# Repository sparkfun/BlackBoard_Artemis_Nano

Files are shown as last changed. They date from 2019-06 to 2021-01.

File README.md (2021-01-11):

**NOTE:** *This product has been retired from our catalog. There is an updated RedBoard version available: [DEV-15443](https://www.sparkfun.com/products/15443). If you are looking for more up-to-date info, please check out some of these resources to see how other users are still hacking and improving on this product version.*

* *[SparkFun Artemis Forum](https://forum.sparkfun.com/viewforum.php?f=167)*
* *[Comments Here on GitHub](https://github.com/sparkfun/BlackBoard_Artemis_Nano/issues)*

SparkFun BlackBoard Artemis Nano
============================

[SparkFun BlackBoard Artemis Nano  
*SparkFun BlackBoard Artemis Nano (SPX-15411)*](https://www.sparkfun.com/products/15411)

We like to joke the Artemis Nano is a party on the front and business on the back. And that's by design! All the important LEDs, connectors, labels, and buttons are presented on the front for the best user experience with all the supporting circuitry on the rear of the board. The BlackBoard Artemis Nano is a minimal but extremely handy implementation of the Artemis module. A light weight, 0.8mm thick PCB, with on board lipo-battery charging and a Qwiic connector, this board is easy to implement into very small projects. A dual row of ground connections make it easy to add lots of buttons, LEDs, and anything that requires its own GND connection. At the same time, the board is breadboard compatible! 

A modern USB-C connector makes programming easy. The Nano is fully compatible with the SparkFun's Arduino core and can be programmed easily under the Arduino IDE. We've also exposed the JTAG connector for more advanced users who prefer to use the power and speed of professional tools. If you're looking for a simple, cost-effective board to replace your aging Arduino Uno or Arduino Nano, look no further. We've even added a digital MEMS microphone for folks wanting to experiment with always-on voice commands with TensorFlow and machine learning.
 
With 1M flash and 384k RAM you'll have plenty of room for your sketches. The Artemis module runs at 48MHz with a 96MHz turbo mode available and with Bluetooth to boot!

The SparkFun Artemis Nano is an incredibly flexible device for a small footprint but if you're looking for all the bells and whistles, be sure to checkout our BlackBoard and ATP footprints for even more I/O and capabilities.

Repository Contents
-------------------
* **/Hardware** - Eagle design files (.brd, .sch)

Documentation
-------------------

* **[Hookup Guide for the BlackBoard Artemis Nano](https://learn.sparkfun.com/tutorials/hookup-guide-for-the-blackboard-artemis-nano)**
* **[Designing with the SparkFun Artemis](https://learn.sparkfun.com/tutorials/designing-with-the-sparkfun-artemis)** - Layout and design considerations when using the Artemis module.
* **[Artemis Development with Arduino](https://learn.sparkfun.com/tutorials/artemis-development-with-arduino)** - Introduction to the Arduino core for the Artemis Module.
* **[Ambiq Apollo3 SDK SetUp](https://learn.sparkfun.com/tutorials/using-sparkfun-edge-board-with-ambiq-apollo3-sdk)** - Getting set up with the Apollo3 Software Development Kit.
* **[CH340E USB to serial IC Drivers](https://www.sparkfun.com/ch340)**
* **[SparkFun Fritzing repo](https://github.com/sparkfun/Fritzing_Parts)** - Fritzing diagrams for SparkFun products.

License Information
-------------------

This product is _**open source**_! 

Please review the LICENSE.md file for license information. 

If you have any questions or concerns on licensing, please contact techsupport@sparkfun.com.

Please use, reuse, and modify these files as you see fit. Please maintain attribution to SparkFun Electronics and release any derivative under the same license.

Distributed as-is; no warranty is given.

- Your friends at SparkFun.

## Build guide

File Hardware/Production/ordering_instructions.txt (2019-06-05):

panel size, 115x97mm
PCB thickness, 0.8mm
number of layers, 4
soldermask color, Red
silkscreen color, White
oz copper, 1oz
finish, HASL lead free
stencils, top+bottom
pcs per panel, 8
min trace width, 0.152400mm / 0.006000in
min drill size, 0.304800mm / 0.012000in
filename to layer stackup 1/2/3/4: GTL, GL2, GL3, GBL

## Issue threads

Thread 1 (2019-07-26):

Cannot upload code

iplayfast, 2019-07-26:
Using Linux.
Artemis SVL Bootloader

phase:	setup
	cleared startup blip
/dev/ttyUSB0 is currently open. Please close any other terminal programs that may be using /dev/ttyUSB0 and try again.
Sketch uses 7348 bytes (0%) of program storage space. Maximum is 960000 bytes.
/home/chris/.arduino15/packages/SparkFun/hardware/apollo3/1.0.4/tools/artemis/linux/artemis_svl /dev/ttyUSB0 -f /tmp/arduino_build_995052/Blink.ino.bin -b 921600 -v

Artemis SVL Bootloader

phase:	setup
	cleared startup blip
/dev/ttyUSB0 is currently open. Please close any other terminal programs that may be using /dev/ttyUSB0 and try again

Opening serial monitor and setting the baud to 9600
shows communication is ok. Shows errors on pins which I'm assuming is from test software missing test bed.

iplayfast, 2019-07-26:
A similar problem with another board was due to flow control problems was worked around by the following python code
`import serial.tools.miniterm
serial.tools.miniterm.main(default_port='/dev/ttyACM0', default_baudrate=115200, default_dtr=False, default_rts=False)

`
Not really a good solution. But perhaps will help you resolve this issue.

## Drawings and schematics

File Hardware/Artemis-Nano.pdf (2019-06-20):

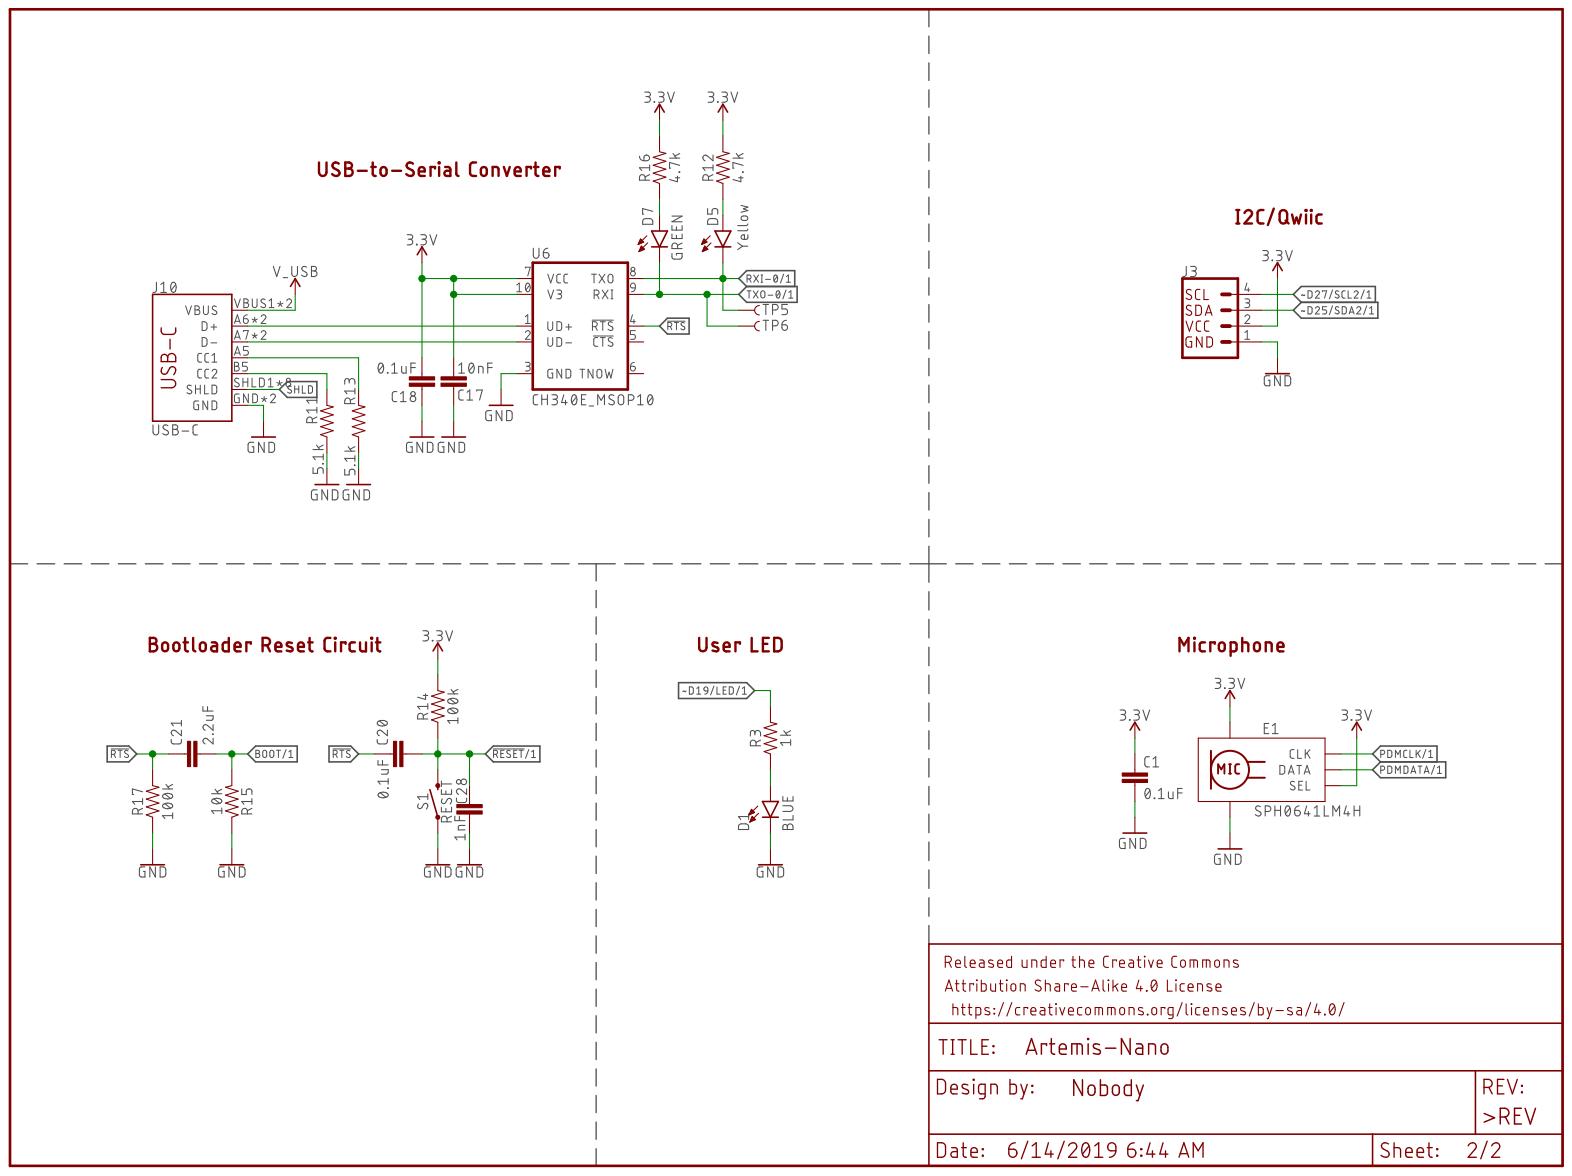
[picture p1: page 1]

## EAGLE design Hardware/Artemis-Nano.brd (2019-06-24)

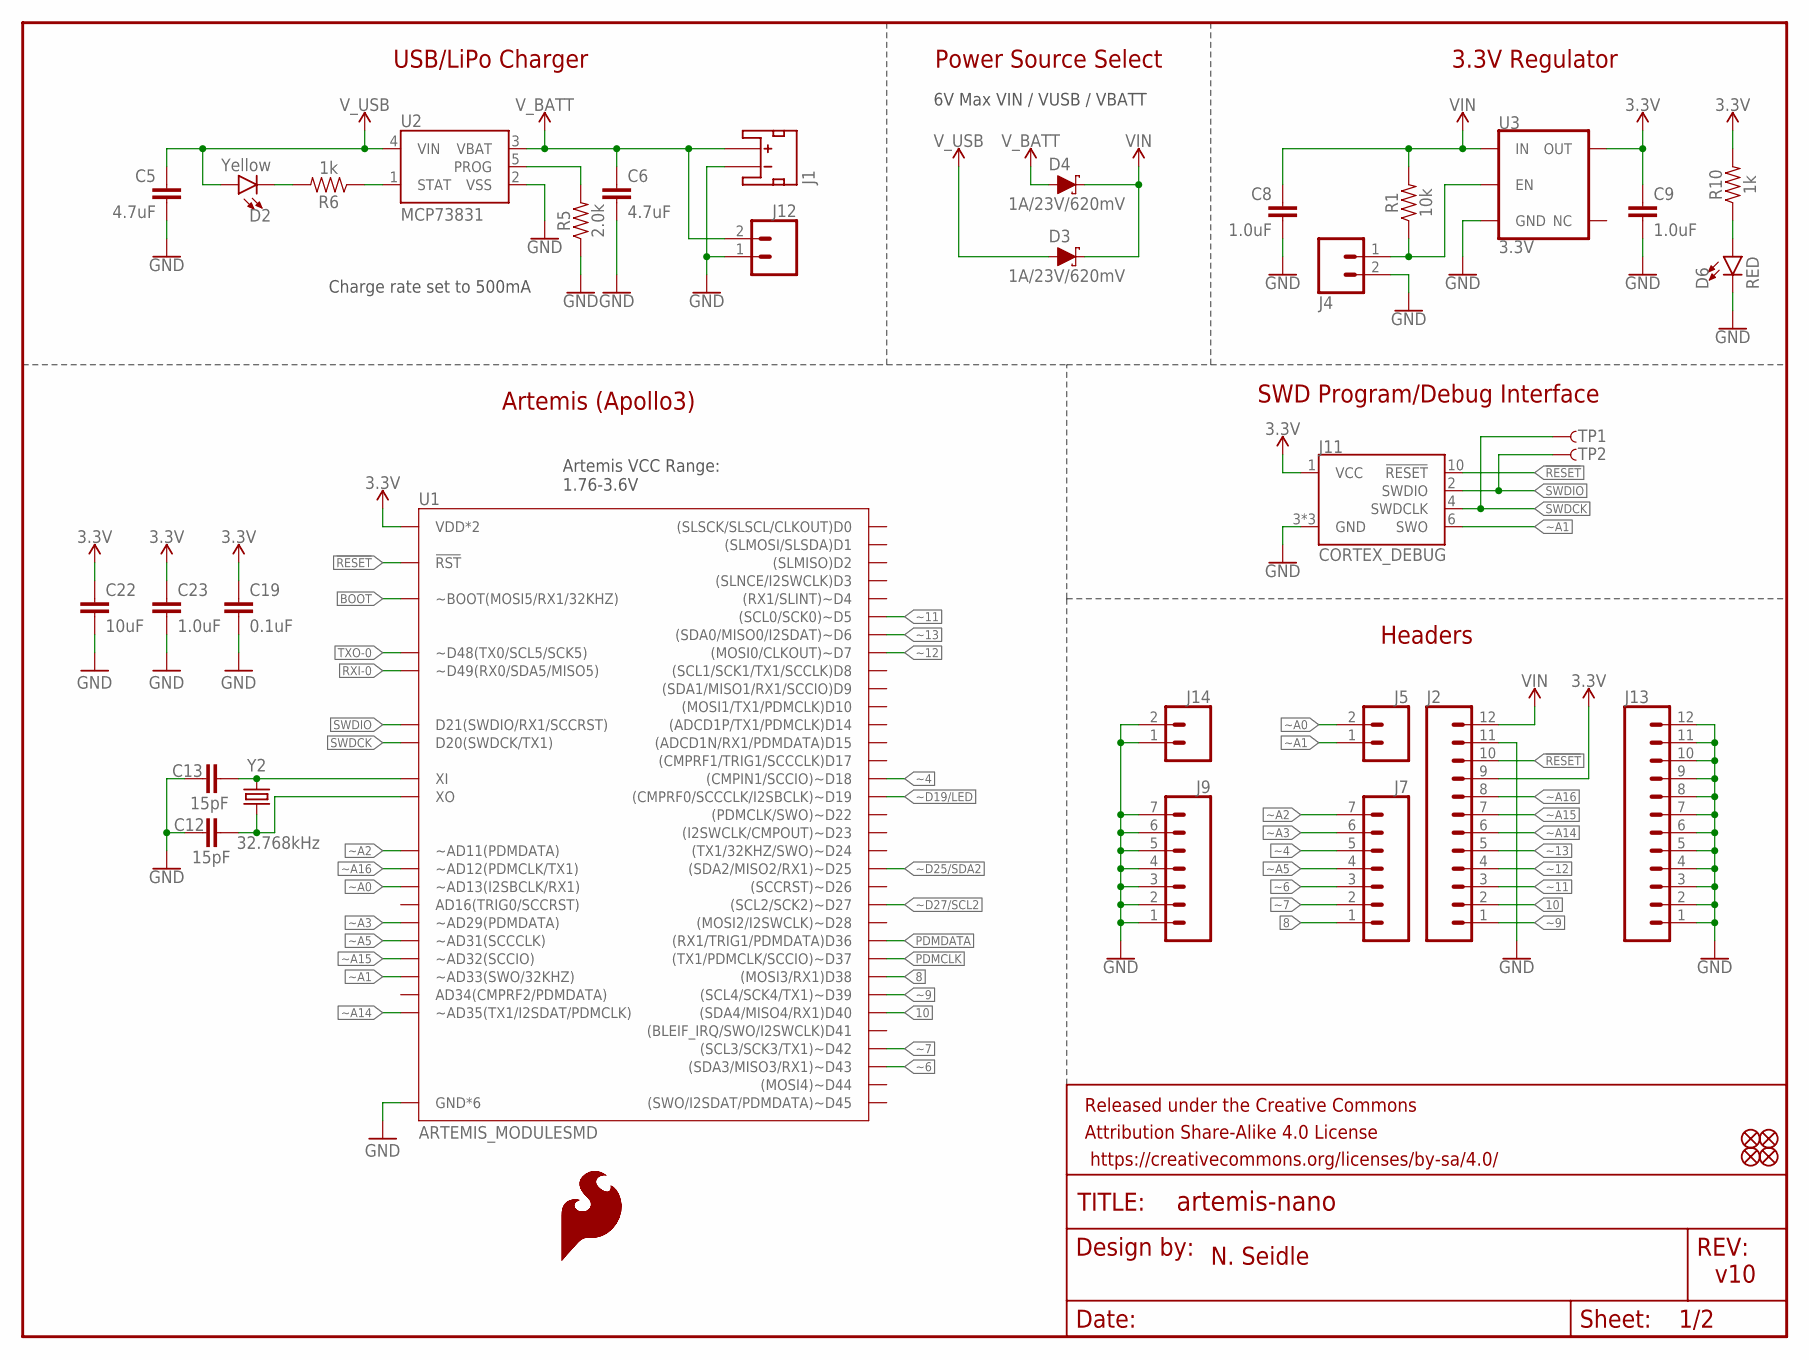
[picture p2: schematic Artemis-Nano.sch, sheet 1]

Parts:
C5, C6: 4.7uF; 0603
C8, C9, C23: 1.0uF; 0402-TIGHT
C12, C13: 15pF; 0603
C19: 0.1uF; 0402-TIGHT
C22: 10uF; 0603
D2: Yellow; LED-0603
D3, D4: 1A/23V/620mV; SOD-323
D6: RED; LED-0603
FD1, FD2, FD3, FD4: FIDUCIALUFIDUCIAL; FIDUCIAL-MICRO
FRAME1: FRAME-LETTER; CREATIVE_COMMONS
J1: JST_2MM_MALE; JST-2-SMD
J2, J13: CONN_12NO_SILK; 1X12_NO_SILK
J4, J5, J12, J14: CONN_021X02_NO_SILK; 1X02_NO_SILK
J7, J9: CONN_07NO_SILK; 1X07_NO_SILK
J11: CORTEX_DEBUG; 2X5-PTH-1.27MM-NO_SILK
LOGO1, LOGO4: SFE_LOGO_FLAME.1_INCH; SFE_LOGO_FLAME_.1
R1: 10k; 0603
R5: 2.0k; 0603
R6, R10: 1k; 0603
TP1, TP2: TEST-POINT3X5; PAD.03X.05
U1: ARTEMIS_MODULESMD; ARTEMIS_FP
U2: MCP73831; SOT23-5
U3: 3.3V; SOT23-5
Y2: 32.768kHz; CRYSTAL-SMD-3.2X1.5MM

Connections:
3.3V: C9.1, C19.2, C22.1, C23.1, J2.9, J11.1 (VCC), R10.2, U1.VDD@36 (VDD*2), U1.VDD@37 (VDD*2), U3.5 (OUT); also elsewhere on the board
8: J7.1, U1.D38 ((MOSI3/RX1)D38)
10: J2.2, U1.D40 ((SDA4/MISO4/RX1)D40)
!RESET: J2.10, J11.10 (!RESET), U1.~RST (!RST); also elsewhere on the board
BOOT: U1.BOOT (~BOOT(MOSI5/RX1/32KHZ)); also elsewhere on the board
GND: C5.2, C6.2, C8.2, C9.2, C12.1, C13.1, C19.1, C22.2, C23.2, D6.C, J1.1 (-), J2.11, J4.2, J9.1, J9.2, J9.3, J9.4, J9.5, J9.6, J9.7, J11.3 (GND), J11.5 (GND), J11.9 (GND), J12.1, J13.1, J13.2, J13.3, J13.4, J13.5, J13.6, J13.7, J13.8, J13.9, J13.10, J13.11, J13.12, J14.1, J14.2, R5.1, U1.GND@1 (GND*6), U1.GND@22 (GND*6), U1.GND@38 (GND*6), U1.GND@39 (GND*6), U1.GND@47 (GND*6), U1.GND@59 (GND*6), U2.2 (VSS), U3.2 (GND); also elsewhere on the board
unnamed: R5.2, U2.5 (PROG)
unnamed: C12.2, U1.XO, Y2.P$2 (2)
unnamed: D2.C, R6.2
unnamed: R6.1, U2.1 (STAT)
unnamed: C13.2, U1.XI, Y2.P$1 (1)
unnamed: D6.A, R10.1
PDMCLK: U1.~D37 ((TX1/PDMCLK/SCCIO)~D37); also elsewhere on the board
PDMDATA: U1.D36 ((RX1/TRIG1/PDMDATA)D36); also elsewhere on the board
RXI-0: U1.RXI-0 (~D49(RX0/SDA5/MISO5)); also elsewhere on the board
SWDCK: J11.4 (SWDCLK), TP1.P$1, U1.SWDCK (D20(SWDCK/TX1))
SWDIO: J11.2 (SWDIO), TP2.P$1, U1.SWDIO (D21(SWDIO/RX1/SCCRST))
TXO-0: U1.TXO-0 (~D48(TX0/SCL5/SCK5)); also elsewhere on the board
VIN: C8.1, D3.C, D4.C, J2.12, R1.2, U3.1 (IN)
VREG_EN: J4.1, R1.1, U3.3 (EN)
V_BATT: C6.1, D4.A, J1.2 (+), J12.2, U2.3 (VBAT)
V_USB: C5.1, D2.A, D3.A, U2.4 (VIN); also elsewhere on the board
~4: J7.5, U1.~D18 ((CMPIN1/SCCIO)~D18)
~6: J7.3, U1.~D43 ((SDA3/MISO3/RX1)~D43)
~7: J7.2, U1.~D42 ((SCL3/SCK3/TX1)~D42)
~9: J2.1, U1.~D39 ((SCL4/SCK4/TX1)~D39)
~11: J2.3, U1.~D5 ((SCL0/SCK0)~D5)
~12: J2.4, U1.D7 ((MOSI0/CLKOUT)~D7)
~13: J2.5, U1.~D6 ((SDA0/MISO0/I2SDAT)~D6)
~A0: J5.2, U1.~AD13 (~AD13(I2SBCLK/RX1))
~A1: J5.1, J11.6 (SWO), U1.~AD33/SWO (~AD33(SWO/32KHZ))
~A2: J7.7, U1.~AD11 (~AD11(PDMDATA))
~A3: J7.6, U1.~AD29 (~AD29(PDMDATA))
~A5: J7.4, U1.~AD31 (~AD31(SCCCLK))
~A14: J2.6, U1.~AD35 (~AD35(TX1/I2SDAT/PDMCLK))
~A15: J2.7, U1.~AD32 (~AD32(SCCIO))
~A16: J2.8, U1.~AD12 (~AD12(PDMCLK/TX1))
~D19/LED: U1.~D19 ((CMPRF0/SCCCLK/I2SBCLK)~D19); also elsewhere on the board
~D25/SDA2: U1.~D25 ((SDA2/MISO2/RX1)~D25); also elsewhere on the board
~D27/SCL2: U1.~D27 ((SCL2/SCK2)~D27); also elsewhere on the board

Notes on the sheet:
v10
N. Seidle
SWD Program/Debug Interface
Headers
Artemis (Apollo3)
USB/LiPo Charger
Power Source Select
3.3V Regulator
Artemis VCC Range: 1.76-3.6V
Charge rate set to 500mA
6V Max VIN / VUSB / VBATT

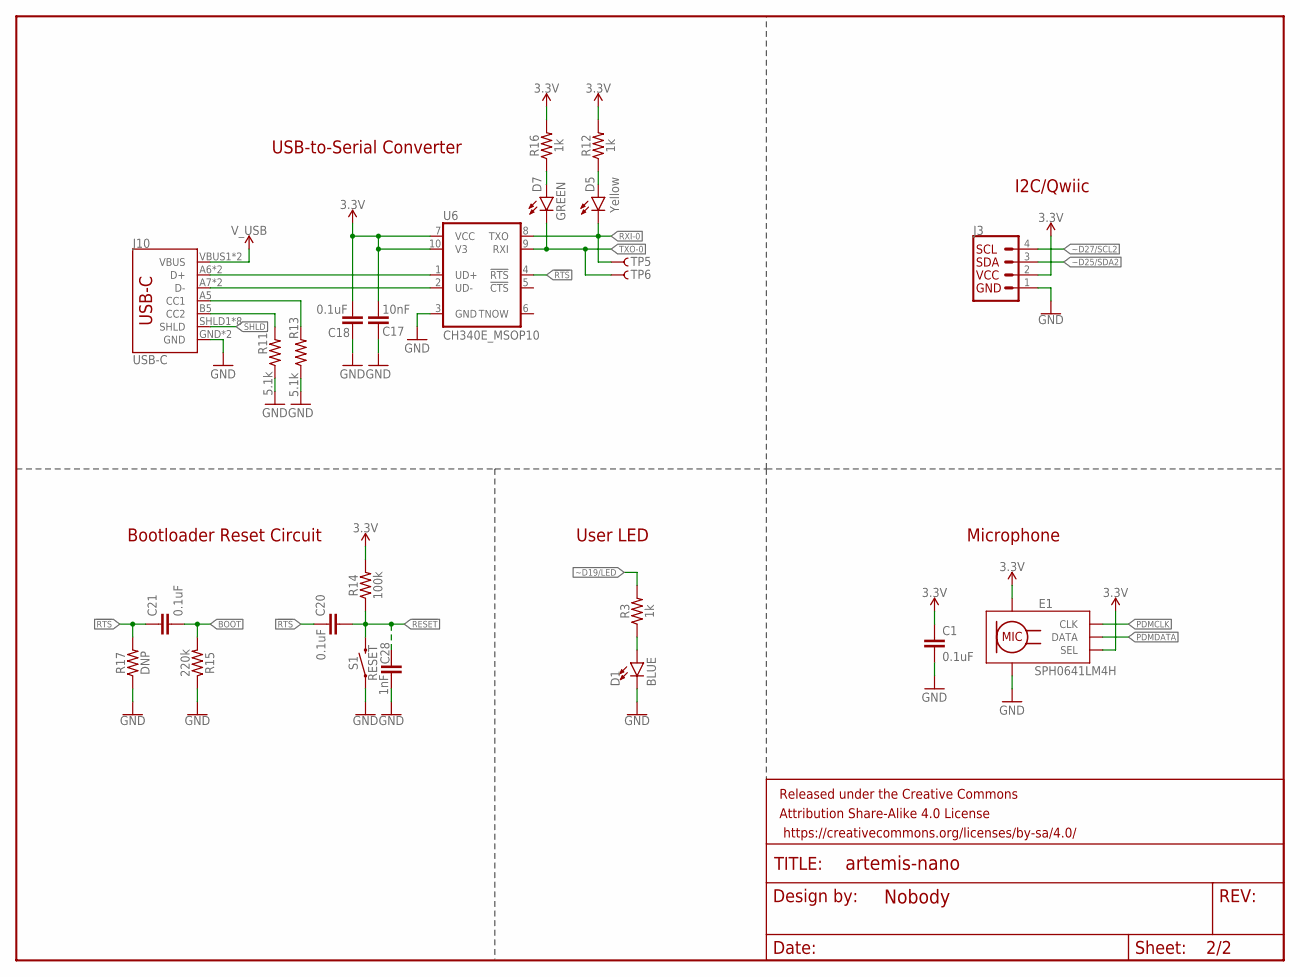
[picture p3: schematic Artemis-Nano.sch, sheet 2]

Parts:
C1: 0.1uF; 0402-TIGHT
C17: 10nF; 0603
C18, C20, C21: 0.1uF; 0603
C28: 1nF; 0603
D1: BLUE; LED-0603
D5: Yellow; LED-0603
D7: GREEN; LED-0603
E1: SPH0641LM4H; SPH0641LM4H-1_MICROPHONE
FRAME2: FRAME-LETTERNO_PACKAGE; DUMMY
J3: QWIIC_CONNECTORJS-1MM; JST04_1MM_RA
J10: USB-C; USB-C-16P
R3, R12, R16: 1k; 0603
R11, R13: 5.1k; 0603
R14: 100k; 0603
R15: 220k; 0603
R17: DNP; 0603
S1: RESET; TACTILE_SWITCH_SMD_4.6X2.8MM
TP5, TP6: TEST-POINT3X5; PAD.03X.05
U6: CH340E_MSOP10; MSOP10

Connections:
3.3V: C1.1, C17.1, C18.1, E1.2 (SEL), E1.5 (VDD), J3.2, R12.2, R14.2, R16.2, U6.7 (VCC), U6.10 (V3); also elsewhere on the board
!RESET: C20.2, C28.1, R14.1, S1.3 (2), S1.4 (2); also elsewhere on the board
!RTS: C20.1, C21.1, R17.2, U6.4 (!RTS)
BOOT: C21.2, R15.2; also elsewhere on the board
CC1: J10.A5 (CC1), R13.2
CC2: J10.B5 (CC2), R11.2
D+1: J10.A6 (D+), J10.B6 (D+), U6.1 (UD+)
D-1: J10.A7 (D-), J10.B7 (D-), U6.2 (UD-)
GND: C1.2, C17.2, C18.2, C28.2, D1.C, E1.3 (GND), E1.6 (GND), E1.7 (GND), E1.8 (GND), J3.1, J10.GND, J10.GND2 (GND), R11.1, R13.1, R15.1, R17.1, S1.1, S1.2 (1), U6.3 (GND); also elsewhere on the board
unnamed: D7.A, R16.1
unnamed: D1.A, R3.1
unnamed: D5.A, R12.1
PDMCLK: E1.4 (CLK); also elsewhere on the board
PDMDATA: E1.1 (DATA); also elsewhere on the board
RXI-0: D5.C, TP5.P$1, U6.8 (TXO); also elsewhere on the board
SHLD: J10.SHLD1 (SHLD), J10.SHLD2 (SHLD), J10.SHLD3 (SHLD), J10.SHLD4 (SHLD), J10.SHLD5 (SHLD), J10.SHLD6 (SHLD), J10.SHLD7 (SHLD), J10.SHLD8 (SHLD)
TXO-0: D7.C, TP6.P$1, U6.9 (RXI); also elsewhere on the board
V_USB: J10.VBUS1 (VBUS), J10.VBUS2 (VBUS); also elsewhere on the board
~D19/LED: R3.2; also elsewhere on the board
~D25/SDA2: J3.3; also elsewhere on the board
~D27/SCL2: J3.4; also elsewhere on the board

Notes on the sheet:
Microphone
USB-to-Serial Converter
Bootloader Reset Circuit
User LED
I2C/Qwiic

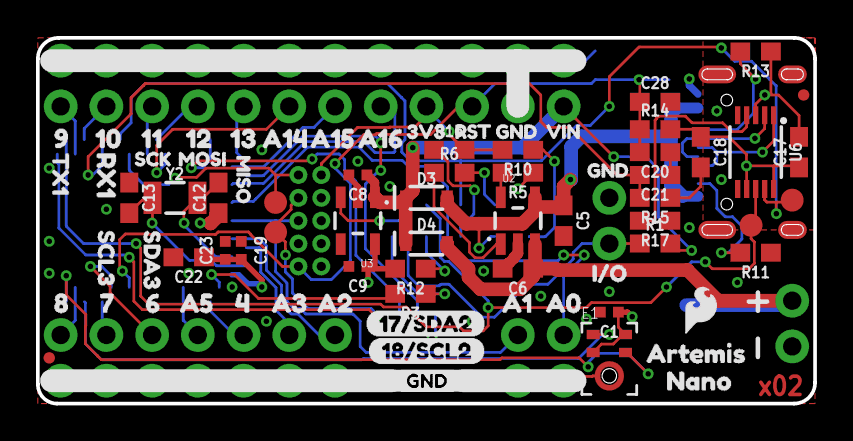
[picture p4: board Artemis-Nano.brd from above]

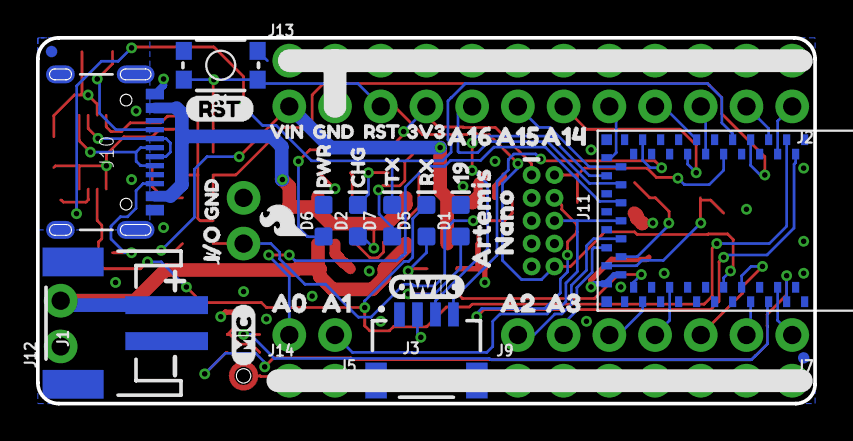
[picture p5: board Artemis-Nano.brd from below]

Board: 4 copper layers, 43.2 x 20.3 mm, 125 parts (47 on the bottom side), 49 nets.

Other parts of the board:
U$1, U$49: 3V316
U$2: ____GND____2
U$3, U$38: RST19
U$4, U$23: I#O3
U$5: CHG26
U$6: PWR27
U$7, U$29, U$33, U$43: GND17
U$8: QWIIC#LOGO#JPG
U$9, U$20: A00
U$10: A57
U$11: SCL30
U$12, U$54: A145
U$13, U$22: ARTEMIS6
U$14: MISO5
U$15: MIC0
U$16: MOSI4
U$17, U$24: NANO7
U$18: SCK3
U$19, U$42: A32
U$21, U$41: A21
U$25: PRODUCTION_INSTRUCTIONS
U$26: 191
U$27, U$39: VIN19
U$28, U$55: A156
U$30: GND2
U$31: SDA31
U$32: 46
U$34, U$40: A10
U$35: 68
U$36: 79
U$37: 810
U$45: 90
U$46: 101
U$47: 112
U$48, U$56: A167
U$50: RX10
U$51: RST1
U$52: 123
U$53: 134
U$57: 17#SDA21
U$59: TX12
U$60: 18#SCL20
U$85: RX23
U$86: TX22

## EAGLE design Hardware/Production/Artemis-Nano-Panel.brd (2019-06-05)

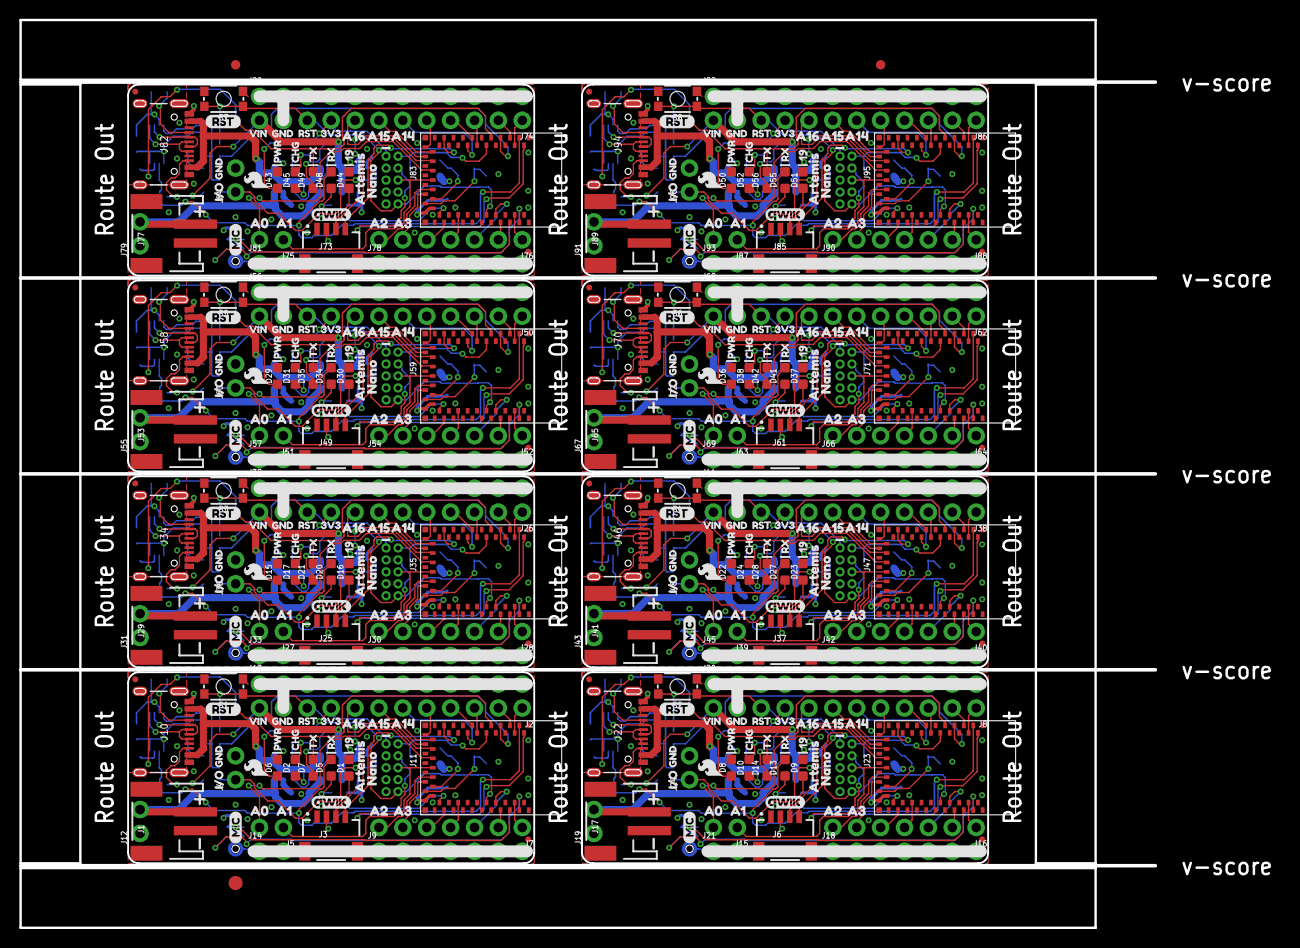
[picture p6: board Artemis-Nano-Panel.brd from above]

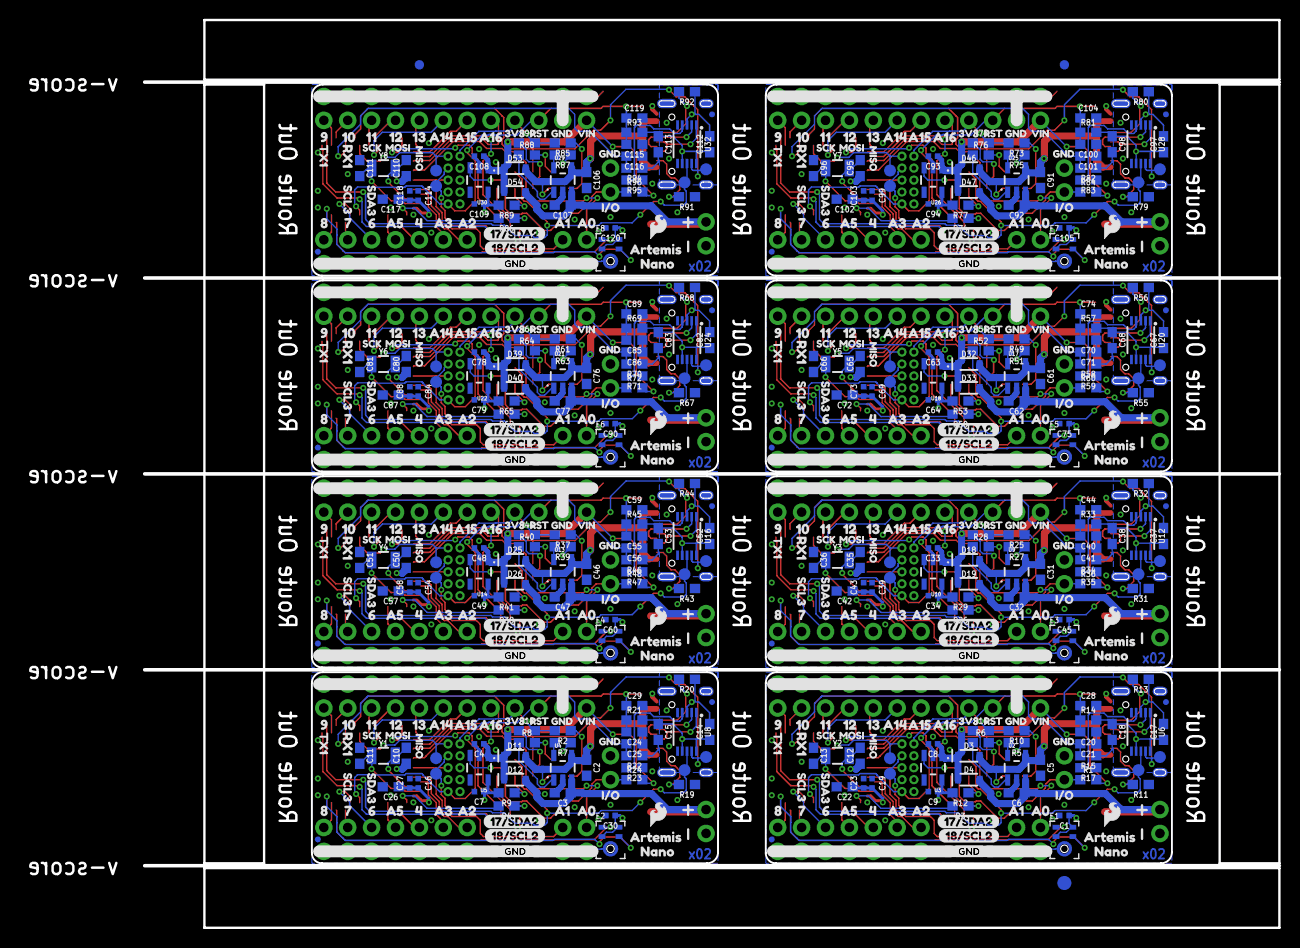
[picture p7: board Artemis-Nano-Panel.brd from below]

Board: 4 copper layers, 120.7 x 96.5 mm, 998 parts (627 on the bottom side), 392 nets.

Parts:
C1, C16, C19, C30, C39, C45, C54, C60, C69, C75, C84, C90, C99, C105, C114, C120: 0.1uF; 0402-TIGHT
C2, C3, C5, C6, C31, C32, C46, C47, C61, C62, C76, C77, C91, C92, C106, C107: 4.7uF; 0603
C4, C7, C8, C9, C23, C27, C33, C34, C43, C48, C49, C58, C63, C64, C73, C78, C79, C88, C93, C94, C103, C108, C109, C118: 1.0uF; 0402-TIGHT
C10, C11, C12, C13, C35, C36, C50, C51, C65, C66, C80, C81, C95, C96, C110, C111: 15pF; 0603
C14, C17, C37, C52, C67, C82, C97, C112: 10nF; 0603
C15, C18, C20, C24, C38, C40, C53, C55, C68, C70, C83, C85, C98, C100, C113, C115: 0.1uF; 0603
C21, C25, C41, C56, C71, C86, C101, C116: 2.2uF; 0603
C22, C26, C42, C57, C72, C87, C102, C117: 10uF; 0603
C28, C29, C44, C59, C74, C89, C104, C119: 1nF; 0603
D1, D9, D16, D23, D30, D37, D44, D51: BLUE; LED-0603
D2, D5, D10, D13, D17, D20, D24, D27, D31, D34, D38, D41, D45, D48, D52, D55: Yellow; LED-0603
D3, D4, D11, D12, D18, D19, D25, D26, D32, D33, D39, D40, D46, D47, D53, D54: 1A/23V/620mV; SOD-323
D6, D8, D15, D22, D29, D36, D43, D50: RED; LED-0603
D7, D14, D21, D28, D35, D42, D49, D56: GREEN; LED-0603
E1, E2, E3, E4, E5, E6, E7, E8: SPH0641LM4H; SPH0641LM4H-1_MICROPHONE
E$1, E$2, E$3, E$4: FIDUCIAL-1X2
E$5, E$6: FIDUCIAL-1.5X3
FD1, FD2, FD3, FD4, FD5, FD6, FD7, FD8, FD9, FD10, FD11, FD12, FD13, FD14, FD15, FD16, FD17, FD18, FD19, FD20, FD21, FD22, FD23, FD24, FD25, FD26, FD27, FD28, FD29, FD30, FD31, FD32: FIDUCIALUFIDUCIAL; FIDUCIAL-MICRO
FRAME1, FRAME2, FRAME3, FRAME4, FRAME5, FRAME6, FRAME7, FRAME8: FRAME-LETTERNO_PACKAGE; DUMMY
J1, J17, J29, J41, J53, J65, J77, J89: JST-2-SMD
J2, J8, J13, J20, J26, J32, J38, J44, J50, J56, J62, J68, J74, J80, J86, J92: 1X12_NO_SILK
J3, J6, J25, J37, J49, J61, J73, J85: JST04_1MM_RA
J4, J5, J12, J14, J15, J19, J21, J24, J27, J31, J33, J36, J39, J43, J45, J48, J51, J55, J57, J60, J63, J67, J69, J72, J75, J79, J81, J84, J87, J91, J93, J96: 1X02_NO_SILK
J7, J9, J16, J18, J28, J30, J40, J42, J52, J54, J64, J66, J76, J78, J88, J90: 1X07_NO_SILK
J10, J22, J34, J46, J58, J70, J82, J94: USB-C; USB-C-16P
J11, J23, J35, J47, J59, J71, J83, J95: CORTEX_DEBUG; 2X5-PTH-1.27MM-NO_SILK
LOGO1, LOGO2, LOGO3, LOGO4, LOGO5, LOGO6, LOGO7, LOGO8, LOGO9, LOGO10, LOGO11, LOGO12, LOGO13, LOGO14, LOGO15, LOGO16: SFE_LOGO_FLAME.1_INCH; SFE_LOGO_FLAME_.1
R1, R15, R22, R24, R34, R36, R46, R48, R58, R60, R70, R72, R82, R84, R94, R96: 10k; 0603
R2, R3, R4, R6, R8, R10, R25, R26, R28, R37, R38, R40, R49, R50, R52, R61, R62, R64, R73, R74, R76, R85, R86, R88: 1k; 0603
R5, R7, R27, R39, R51, R63, R75, R87: 2.0k; 0603
R9, R12, R16, R18, R29, R30, R41, R42, R53, R54, R65, R66, R77, R78, R89, R90: 4.7k; 0603
R11, R13, R19, R20, R31, R32, R43, R44, R55, R56, R67, R68, R79, R80, R91, R92: 5.1k; 0603
R14, R17, R21, R23, R33, R35, R45, R47, R57, R59, R69, R71, R81, R83, R93, R95: 100k; 0603
S1, S2, S3, S4, S5, S6, S7, S8: RESET; TACTILE_SWITCH_SMD_4.6X2.8MM
TP1, TP2, TP7, TP8, TP11, TP12, TP15, TP16, TP19, TP20, TP23, TP24, TP27, TP28, TP31, TP32: PAD.03X.05
TP3, TP4, TP5, TP6, TP9, TP10, TP13, TP14, TP17, TP18, TP21, TP22, TP25, TP26, TP29, TP30: TEST-POINT3X5; PAD.03X.05
U1, U7, U11, U15, U19, U23, U27, U31: ARTEMIS_MODULESMD; ARTEMIS_FP
U2, U4, U9, U13, U17, U21, U25, U29: MCP73831; SOT23-5
U3, U5, U10, U14, U18, U22, U26, U30: 3.3V; SOT23-5
U6, U8, U12, U16, U20, U24, U28, U32: CH340E_MSOP10; MSOP10
U$1, U$49, U$65, U$72, U$127, U$134, U$187, U$194, U$247, U$254, U$307, U$314, U$367, U$374, U$427, U$434: 3V316
U$2, U$82, U$144, U$204, U$264, U$324, U$384, U$444: ____GND____2
U$3, U$38, U$64, U$70, U$126, U$132, U$186, U$192, U$246, U$252, U$306, U$312, U$366, U$372, U$426, U$432: RST19
U$4, U$23, U$117, U$119, U$177, U$179, U$237, U$239, U$297, U$299, U$357, U$359, U$417, U$419, U$477, U$479: I#O3
U$5, U$44, U$121, U$181, U$241, U$301, U$361, U$421: CHG26
U$6, U$58, U$122, U$182, U$242, U$302, U$362, U$422: PWR27
U$7, U$29, U$33, U$43, U$62, U$69, U$118, U$120, U$124, U$131, U$178, U$180, U$184, U$191, U$238, U$240, U$244, U$251, U$298, U$300, U$304, U$311, U$358, U$360, U$364, U$371, U$418, U$420, U$424, U$431, U$478, U$480: GND17
U$8, U$61, U$123, U$183, U$243, U$303, U$363, U$423: QWIIC#LOGO#JPG
U$9, U$20, U$84, U$108, U$146, U$168, U$206, U$228, U$266, U$288, U$326, U$348, U$386, U$408, U$446, U$468: A00
U$10, U$105, U$165, U$225, U$285, U$345, U$405, U$465: A57
U$11, U$102, U$162, U$222, U$282, U$342, U$402, U$462: SCL30
U$12, U$54, U$99, U$110, U$159, U$170, U$219, U$230, U$279, U$290, U$339, U$350, U$399, U$410, U$459, U$470: A145
U$13, U$22, U$73, U$79, U$135, U$141, U$195, U$201, U$255, U$261, U$315, U$321, U$375, U$381, U$435, U$441: ARTEMIS6
U$14, U$75, U$137, U$197, U$257, U$317, U$377, U$437: MISO5
U$15, U$74, U$136, U$196, U$256, U$316, U$376, U$436: MIC0
U$16, U$76, U$138, U$198, U$258, U$318, U$378, U$438: MOSI4
U$17, U$24, U$77, U$80, U$139, U$142, U$199, U$202, U$259, U$262, U$319, U$322, U$379, U$382, U$439, U$442: NANO7
U$18, U$78, U$140, U$200, U$260, U$320, U$380, U$440: SCK3
U$19, U$42, U$93, U$106, U$153, U$166, U$213, U$226, U$273, U$286, U$333, U$346, U$393, U$406, U$453, U$466: A32
U$21, U$41, U$92, U$107, U$152, U$167, U$212, U$227, U$272, U$287, U$332, U$347, U$392, U$407, U$452, U$467: A21
U$25, U$83, U$145, U$205, U$265, U$325, U$385, U$445: PRODUCTION_INSTRUCTIONS
U$26, U$116, U$176, U$236, U$296, U$356, U$416, U$476: 191
U$27, U$39, U$63, U$71, U$125, U$133, U$185, U$193, U$245, U$253, U$305, U$313, U$365, U$373, U$425, U$433: VIN19
U$28, U$55, U$100, U$111, U$160, U$171, U$220, U$231, U$280, U$291, U$340, U$351, U$400, U$411, U$460, U$471: A156
U$30, U$81, U$143, U$203, U$263, U$323, U$383, U$443: GND2
U$31, U$103, U$163, U$223, U$283, U$343, U$403, U$463: SDA31
U$32, U$87, U$147, U$207, U$267, U$327, U$387, U$447: 46
U$34, U$40, U$91, U$109, U$151, U$169, U$211, U$229, U$271, U$289, U$331, U$349, U$391, U$409, U$451, U$469: A10
U$35, U$88, U$148, U$208, U$268, U$328, U$388, U$448: 68
U$36, U$89, U$149, U$209, U$269, U$329, U$389, U$449: 79
U$37, U$90, U$150, U$210, U$270, U$330, U$390, U$450: 810
U$45, U$94, U$154, U$214, U$274, U$334, U$394, U$454: 90
U$46, U$95, U$155, U$215, U$275, U$335, U$395, U$455: 101
U$47, U$96, U$156, U$216, U$276, U$336, U$396, U$456: 112
U$48, U$56, U$101, U$112, U$161, U$172, U$221, U$232, U$281, U$292, U$341, U$352, U$401, U$412, U$461, U$472: A167
U$50, U$113, U$173, U$233, U$293, U$353, U$413, U$473: RX10
U$51, U$66, U$128, U$188, U$248, U$308, U$368, U$428: RST1
U$52, U$97, U$157, U$217, U$277, U$337, U$397, U$457: 123
U$53, U$98, U$158, U$218, U$278, U$338, U$398, U$458: 134
U$57, U$114, U$174, U$234, U$294, U$354, U$414, U$474: 17#SDA21
U$59, U$104, U$164, U$224, U$284, U$344, U$404, U$464: TX12
U$60, U$115, U$175, U$235, U$295, U$355, U$415, U$475: 18#SCL20
U$67, U$85, U$129, U$189, U$249, U$309, U$369, U$429: RX23
U$68, U$86, U$130, U$190, U$250, U$310, U$370, U$430: TX22
Y1, Y2, Y3, Y4, Y5, Y6, Y7, Y8: 32.768kHz; CRYSTAL-SMD-3.2X1.5MM

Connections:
1: J16.1, U7.D38
2: J8.2, U7.D40
3: J28.1, U11.D38
3.3V: C1.1, C9.1, C17.1, C18.1, C19.2, C22.1, C23.1, E1.2, E1.5, J2.9, J3.2, J11.1, R10.2, R12.2, R14.2, R16.2, U1.VDD@36, U1.VDD@37, U3.5, U6.7, U6.10
3.3V1: C7.1, C14.1, C15.1, C16.2, C26.1, C27.1, C30.1, E2.2, E2.5, J6.2, J8.9, J23.1, R2.2, R9.2, R18.2, R21.2, U5.5, U7.VDD@36, U7.VDD@37, U8.7, U8.10
3.3V2: C34.1, C37.1, C38.1, C39.2, C42.1, C43.1, C45.1, E3.2, E3.5, J25.2, J26.9, J35.1, R25.2, R29.2, R30.2, R33.2, U10.5, U11.VDD@36, U11.VDD@37, U12.7, U12.10
3.3V3: C49.1, C52.1, C53.1, C54.2, C57.1, C58.1, C60.1, E4.2, E4.5, J37.2, J38.9, J47.1, R37.2, R41.2, R42.2, R45.2, U14.5, U15.VDD@36, U15.VDD@37, U16.7, U16.10
3.3V4: C64.1, C67.1, C68.1, C69.2, C72.1, C73.1, C75.1, E5.2, E5.5, J49.2, J50.9, J59.1, R49.2, R53.2, R54.2, R57.2, U18.5, U19.VDD@36, U19.VDD@37, U20.7, U20.10
3.3V5: C79.1, C82.1, C83.1, C84.2, C87.1, C88.1, C90.1, E6.2, E6.5, J61.2, J62.9, J71.1, R61.2, R65.2, R66.2, R69.2, U22.5, U23.VDD@36, U23.VDD@37, U24.7, U24.10
3.3V6: C94.1, C97.1, C98.1, C99.2, C102.1, C103.1, C105.1, E7.2, E7.5, J73.2, J74.9, J83.1, R73.2, R77.2, R78.2, R81.2, U26.5, U27.VDD@36, U27.VDD@37, U28.7, U28.10
3.3V7: C109.1, C112.1, C113.1, C114.2, C117.1, C118.1, C120.1, E8.2, E8.5, J85.2, J86.9, J95.1, R85.2, R89.2, R90.2, R93.2, U30.5, U31.VDD@36, U31.VDD@37, U32.7, U32.10
4: J26.2, U11.D40
5: J40.1, U15.D38
6: J38.2, U15.D40
7: J52.1, U19.D38
8: J7.1, U1.D38
9: J50.2, U19.D40
10: J2.2, U1.D40
11: J64.1, U23.D38
12: J62.2, U23.D40
13: J76.1, U27.D38
14: J74.2, U27.D40
15: J88.1, U31.D38
16: J86.2, U31.D40
!RESET: C20.2, C28.1, J2.10, J11.10, R14.1, S1.3, S1.4, U1.~RST
!RESET1: C24.2, C29.1, J8.10, J23.10, R21.1, S2.3, S2.4, U7.~RST
!RESET2: C40.2, C44.1, J26.10, J35.10, R33.1, S3.3, S3.4, U11.~RST
!RESET3: C55.2, C59.1, J38.10, J47.10, R45.1, S4.3, S4.4, U15.~RST
!RESET4: C70.2, C74.1, J50.10, J59.10, R57.1, S5.3, S5.4, U19.~RST
!RESET5: C85.2, C89.1, J62.10, J71.10, R69.1, S6.3, S6.4, U23.~RST
!RESET6: C100.2, C104.1, J74.10, J83.10, R81.1, S7.3, S7.4, U27.~RST
!RESET7: C115.2, C119.1, J86.10, J95.10, R93.1, S8.3, S8.4, U31.~RST
!RTS: C20.1, C21.1, R17.2, U6.4
!RTS1: C24.1, C25.1, R23.2, U8.4
!RTS2: C40.1, C41.1, R35.2, U12.4
!RTS3: C55.1, C56.1, R47.2, U16.4
!RTS4: C70.1, C71.1, R59.2, U20.4
!RTS5: C85.1, C86.1, R71.2, U24.4
!RTS6: C100.1, C101.1, R83.2, U28.4
!RTS7: C115.1, C116.1, R95.2, U32.4
BOOT: C21.2, R15.2, U1.BOOT
BOOT1: C25.2, R22.2, U7.BOOT
BOOT2: C41.2, R34.2, U11.BOOT
BOOT3: C56.2, R46.2, U15.BOOT
BOOT4: C71.2, R58.2, U19.BOOT
BOOT5: C86.2, R70.2, U23.BOOT
BOOT6: C101.2, R82.2, U27.BOOT
BOOT7: C116.2, R94.2, U31.BOOT
CC1: J10.A5, R13.2
CC2: J10.B5, R11.2
CC3: J22.B5, R19.2
CC4: J22.A5, R20.2
CC5: J34.B5, R31.2
CC6: J34.A5, R32.2
CC7: J46.B5, R43.2
CC8: J46.A5, R44.2
CC9: J58.B5, R55.2
CC10: J58.A5, R56.2
CC11: J70.B5, R67.2
CC12: J70.A5, R68.2
CC13: J82.B5, R79.2
CC14: J82.A5, R80.2
CC15: J94.B5, R91.2
CC16: J94.A5, R92.2
D+1: J10.A6, J10.B6, U6.1
D+2: J22.A6, J22.B6, U8.1
D+3: J34.A6, J34.B6, U12.1
D+4: J46.A6, J46.B6, U16.1
D+5: J58.A6, J58.B6, U20.1
D+6: J70.A6, J70.B6, U24.1
D+7: J82.A6, J82.B6, U28.1
D+8: J94.A6, J94.B6, U32.1
D-1: J10.A7, J10.B7, U6.2
D-2: J22.A7, J22.B7, U8.2
D-3: J34.A7, J34.B7, U12.2
D-4: J46.A7, J46.B7, U16.2
D-5: J58.A7, J58.B7, U20.2
D-6: J70.A7, J70.B7, U24.2
D-7: J82.A7, J82.B7, U28.2
D-8: J94.A7, J94.B7, U32.2
GND: C1.2, C5.2, C6.2, C8.2, C9.2, C12.1, C13.1, C17.2, C18.2, C19.1, C22.2, C23.2, C28.2, D1.C, D6.C, E1.3, E1.6, E1.7, E1.8, J1.1, J2.11, J3.1, J4.2, J9.1, J9.2, J9.3, J9.4, J9.5, J9.6, J9.7, J10.GND, J10.GND2, J11.3, J11.5, J11.9, J12.1, J13.1, J13.2, J13.3, J13.4, J13.5, J13.6, J13.7, J13.8, J13.9, J13.10, J13.11, J13.12, J14.1, J14.2, R5.1, R11.1, R13.1, R15.1, R17.1, S1.1, S1.2, U1.GND@1, U1.GND@22, U1.GND@38, U1.GND@39, U1.GND@47, U1.GND@59, U2.2, U3.2, U6.3
GND1: C2.2, C3.2, C4.2, C7.2, C10.1, C11.1, C14.2, C15.2, C16.1, C26.2, C27.2, C29.2, C30.2, D8.C, D9.C, E2.3, E2.6, E2.7, E2.8, J6.1, J8.11, J17.1, J18.1, J18.2, J18.3, J18.4, J18.5, J18.6, J18.7, J19.1, J20.1, J20.2, J20.3, J20.4, J20.5, J20.6, J20.7, J20.8, J20.9, J20.10, J20.11, J20.12, J21.1, J21.2, J22.GND, J22.GND2, J23.3, J23.5, J23.9, J24.2, R7.1, R19.1, R20.1, R22.1, R23.1, S2.1, S2.2, U4.2, U5.2, U7.GND@1, U7.GND@22, U7.GND@38, U7.GND@39, U7.GND@47, U7.GND@59, U8.3
GND2: C31.2, C32.2, C33.2, C34.2, C35.1, C36.1, C37.2, C38.2, C39.1, C42.2, C43.2, C44.2, C45.2, D15.C, D16.C, E3.3, E3.6, E3.7, E3.8, J25.1, J26.11, J29.1, J30.1, J30.2, J30.3, J30.4, J30.5, J30.6, J30.7, J31.1, J32.1, J32.2, J32.3, J32.4, J32.5, J32.6, J32.7, J32.8, J32.9, J32.10, J32.11, J32.12, J33.1, J33.2, J34.GND, J34.GND2, J35.3, J35.5, J35.9, J36.2, R27.1, R31.1, R32.1, R34.1, R35.1, S3.1, S3.2, U9.2, U10.2, U11.GND@1, U11.GND@22, U11.GND@38, U11.GND@39, U11.GND@47, U11.GND@59, U12.3
GND3: C46.2, C47.2, C48.2, C49.2, C50.1, C51.1, C52.2, C53.2, C54.1, C57.2, C58.2, C59.2, C60.2, D22.C, D23.C, E4.3, E4.6, E4.7, E4.8, J37.1, J38.11, J41.1, J42.1, J42.2, J42.3, J42.4, J42.5, J42.6, J42.7, J43.1, J44.1, J44.2, J44.3, J44.4, J44.5, J44.6, J44.7, J44.8, J44.9, J44.10, J44.11, J44.12, J45.1, J45.2, J46.GND, J46.GND2, J47.3, J47.5, J47.9, J48.2, R39.1, R43.1, R44.1, R46.1, R47.1, S4.1, S4.2, U13.2, U14.2, U15.GND@1, U15.GND@22, U15.GND@38, U15.GND@39, U15.GND@47, U15.GND@59, U16.3
GND4: C61.2, C62.2, C63.2, C64.2, C65.1, C66.1, C67.2, C68.2, C69.1, C72.2, C73.2, C74.2, C75.2, D29.C, D30.C, E5.3, E5.6, E5.7, E5.8, J49.1, J50.11, J53.1, J54.1, J54.2, J54.3, J54.4, J54.5, J54.6, J54.7, J55.1, J56.1, J56.2, J56.3, J56.4, J56.5, J56.6, J56.7, J56.8, J56.9, J56.10, J56.11, J56.12, J57.1, J57.2, J58.GND, J58.GND2, J59.3, J59.5, J59.9, J60.2, R51.1, R55.1, R56.1, R58.1, R59.1, S5.1, S5.2, U17.2, U18.2, U19.GND@1, U19.GND@22, U19.GND@38, U19.GND@39, U19.GND@47, U19.GND@59, U20.3
GND5: C76.2, C77.2, C78.2, C79.2, C80.1, C81.1, C82.2, C83.2, C84.1, C87.2, C88.2, C89.2, C90.2, D36.C, D37.C, E6.3, E6.6, E6.7, E6.8, J61.1, J62.11, J65.1, J66.1, J66.2, J66.3, J66.4, J66.5, J66.6, J66.7, J67.1, J68.1, J68.2, J68.3, J68.4, J68.5, J68.6, J68.7, J68.8, J68.9, J68.10, J68.11, J68.12, J69.1, J69.2, J70.GND, J70.GND2, J71.3, J71.5, J71.9, J72.2, R63.1, R67.1, R68.1, R70.1, R71.1, S6.1, S6.2, U21.2, U22.2, U23.GND@1, U23.GND@22, U23.GND@38, U23.GND@39, U23.GND@47, U23.GND@59, U24.3
GND6: C91.2, C92.2, C93.2, C94.2, C95.1, C96.1, C97.2, C98.2, C99.1, C102.2, C103.2, C104.2, C105.2, D43.C, D44.C, E7.3, E7.6, E7.7, E7.8, J73.1, J74.11, J77.1, J78.1, J78.2, J78.3, J78.4, J78.5, J78.6, J78.7, J79.1, J80.1, J80.2, J80.3, J80.4, J80.5, J80.6, J80.7, J80.8, J80.9, J80.10, J80.11, J80.12, J81.1, J81.2, J82.GND, J82.GND2, J83.3, J83.5, J83.9, J84.2, R75.1, R79.1, R80.1, R82.1, R83.1, S7.1, S7.2, U25.2, U26.2, U27.GND@1, U27.GND@22, U27.GND@38, U27.GND@39, U27.GND@47, U27.GND@59, U28.3
GND7: C106.2, C107.2, C108.2, C109.2, C110.1, C111.1, C112.2, C113.2, C114.1, C117.2, C118.2, C119.2, C120.2, D50.C, D51.C, E8.3, E8.6, E8.7, E8.8, J85.1, J86.11, J89.1, J90.1, J90.2, J90.3, J90.4, J90.5, J90.6, J90.7, J91.1, J92.1, J92.2, J92.3, J92.4, J92.5, J92.6, J92.7, J92.8, J92.9, J92.10, J92.11, J92.12, J93.1, J93.2, J94.GND, J94.GND2, J95.3, J95.5, J95.9, J96.2, R87.1, R91.1, R92.1, R94.1, R95.1, S8.1, S8.2, U29.2, U30.2, U31.GND@1, U31.GND@22, U31.GND@38, U31.GND@39, U31.GND@47, U31.GND@59, U32.3
unnamed: R5.2, U2.5
unnamed: C12.2, U1.XO, Y2.P$2
unnamed: D2.C, R6.2
unnamed: R6.1, U2.1
unnamed: D7.A, R16.1
unnamed: D8.A, R2.1
unnamed: D1.A, R3.1
unnamed: C13.2, U1.XI, Y2.P$1
unnamed: D5.A, R12.1
unnamed: D6.A, R10.1
unnamed: D9.A, R4.1
unnamed: R7.2, U4.5
unnamed: D10.C, R8.2
unnamed: R8.1, U4.1
unnamed: C10.2, U7.XO, Y1.P$2
unnamed: C11.2, U7.XI, Y1.P$1
unnamed: D14.A, R18.1
unnamed: D13.A, R9.1
unnamed: D15.A, R25.1
unnamed: D16.A, R26.1
unnamed: R27.2, U9.5
unnamed: D17.C, R28.2
unnamed: R28.1, U9.1
unnamed: C35.2, U11.XO, Y3.P$2
unnamed: C36.2, U11.XI, Y3.P$1
unnamed: D21.A, R30.1
unnamed: D20.A, R29.1
unnamed: D22.A, R37.1
unnamed: D23.A, R38.1
unnamed: R39.2, U13.5
unnamed: D24.C, R40.2
unnamed: R40.1, U13.1
unnamed: C50.2, U15.XO, Y4.P$2
unnamed: C51.2, U15.XI, Y4.P$1
unnamed: D28.A, R42.1
unnamed: D27.A, R41.1
unnamed: D29.A, R49.1
unnamed: D30.A, R50.1
unnamed: R51.2, U17.5
unnamed: D31.C, R52.2
unnamed: R52.1, U17.1
unnamed: C65.2, U19.XO, Y5.P$2
unnamed: C66.2, U19.XI, Y5.P$1
unnamed: D35.A, R54.1
unnamed: D34.A, R53.1
unnamed: D36.A, R61.1
unnamed: D37.A, R62.1
unnamed: R63.2, U21.5
unnamed: D38.C, R64.2
unnamed: R64.1, U21.1
unnamed: C80.2, U23.XO, Y6.P$2
unnamed: C81.2, U23.XI, Y6.P$1
unnamed: D42.A, R66.1
unnamed: D41.A, R65.1
unnamed: D43.A, R73.1
unnamed: D44.A, R74.1
unnamed: R75.2, U25.5
unnamed: D45.C, R76.2
unnamed: R76.1, U25.1
unnamed: C95.2, U27.XO, Y7.P$2
unnamed: C96.2, U27.XI, Y7.P$1
unnamed: D49.A, R78.1
unnamed: D48.A, R77.1
unnamed: D50.A, R85.1
unnamed: D51.A, R86.1
unnamed: R87.2, U29.5
unnamed: D52.C, R88.2
unnamed: R88.1, U29.1
unnamed: C110.2, U31.XO, Y8.P$2
unnamed: C111.2, U31.XI, Y8.P$1
unnamed: D56.A, R90.1
unnamed: D55.A, R89.1
PDMCLK: E1.4, U1.~D37
PDMCLK1: E2.4, U7.~D37
PDMCLK2: E3.4, U11.~D37
PDMCLK3: E4.4, U15.~D37
PDMCLK4: E5.4, U19.~D37
PDMCLK5: E6.4, U23.~D37
PDMCLK6: E7.4, U27.~D37
PDMCLK7: E8.4, U31.~D37
PDMDATA: E1.1, U1.D36
PDMDATA1: E2.1, U7.D36
PDMDATA2: E3.1, U11.D36
PDMDATA3: E4.1, U15.D36
PDMDATA4: E5.1, U19.D36
PDMDATA5: E6.1, U23.D36
PDMDATA6: E7.1, U27.D36
PDMDATA7: E8.1, U31.D36
RXI-0: D5.C, TP5.P$1, U1.RXI-0, U6.8
RXI-1: D13.C, TP3.P$1, U7.RXI-0, U8.8
RXI-2: D20.C, TP9.P$1, U11.RXI-0, U12.8
RXI-3: D27.C, TP13.P$1, U15.RXI-0, U16.8
RXI-4: D34.C, TP17.P$1, U19.RXI-0, U20.8
RXI-5: D41.C, TP21.P$1, U23.RXI-0, U24.8
RXI-6: D48.C, TP25.P$1, U27.RXI-0, U28.8
RXI-7: D55.C, TP29.P$1, U31.RXI-0, U32.8
SHLD: J10.SHLD1, J10.SHLD2, J10.SHLD3, J10.SHLD4, J10.SHLD5, J10.SHLD6, J10.SHLD7, J10.SHLD8
SHLD1: J22.SHLD1, J22.SHLD2, J22.SHLD3, J22.SHLD4, J22.SHLD5, J22.SHLD6, J22.SHLD7, J22.SHLD8
SHLD2: J34.SHLD1, J34.SHLD2, J34.SHLD3, J34.SHLD4, J34.SHLD5, J34.SHLD6, J34.SHLD7, J34.SHLD8
SHLD3: J46.SHLD1, J46.SHLD2, J46.SHLD3, J46.SHLD4, J46.SHLD5, J46.SHLD6, J46.SHLD7, J46.SHLD8
SHLD4: J58.SHLD1, J58.SHLD2, J58.SHLD3, J58.SHLD4, J58.SHLD5, J58.SHLD6, J58.SHLD7, J58.SHLD8
SHLD5: J70.SHLD1, J70.SHLD2, J70.SHLD3, J70.SHLD4, J70.SHLD5, J70.SHLD6, J70.SHLD7, J70.SHLD8
SHLD6: J82.SHLD1, J82.SHLD2, J82.SHLD3, J82.SHLD4, J82.SHLD5, J82.SHLD6, J82.SHLD7, J82.SHLD8
SHLD7: J94.SHLD1, J94.SHLD2, J94.SHLD3, J94.SHLD4, J94.SHLD5, J94.SHLD6, J94.SHLD7, J94.SHLD8
SWDCK: J11.4, TP1.P$1, U1.SWDCK
SWDCK1: J23.4, TP7.P$1, U7.SWDCK
SWDCK2: J35.4, TP11.P$1, U11.SWDCK
SWDCK3: J47.4, TP15.P$1, U15.SWDCK
SWDCK4: J59.4, TP19.P$1, U19.SWDCK
SWDCK5: J71.4, TP23.P$1, U23.SWDCK
SWDCK6: J83.4, TP27.P$1, U27.SWDCK
SWDCK7: J95.4, TP31.P$1, U31.SWDCK
SWDIO: J11.2, TP2.P$1, U1.SWDIO
SWDIO1: J23.2, TP8.P$1, U7.SWDIO
SWDIO2: J35.2, TP12.P$1, U11.SWDIO
SWDIO3: J47.2, TP16.P$1, U15.SWDIO
SWDIO4: J59.2, TP20.P$1, U19.SWDIO
SWDIO5: J71.2, TP24.P$1, U23.SWDIO
SWDIO6: J83.2, TP28.P$1, U27.SWDIO
SWDIO7: J95.2, TP32.P$1, U31.SWDIO
TXO-0: D7.C, TP6.P$1, U1.TXO-0, U6.9
TXO-1: D14.C, TP4.P$1, U7.TXO-0, U8.9
TXO-2: D21.C, TP10.P$1, U11.TXO-0, U12.9
TXO-3: D28.C, TP14.P$1, U15.TXO-0, U16.9
TXO-4: D35.C, TP18.P$1, U19.TXO-0, U20.9
TXO-5: D42.C, TP22.P$1, U23.TXO-0, U24.9
TXO-6: D49.C, TP26.P$1, U27.TXO-0, U28.9
TXO-7: D56.C, TP30.P$1, U31.TXO-0, U32.9
VIN: C8.1, D3.C, D4.C, J2.12, R1.2, U3.1
VIN1: C4.1, D11.C, D12.C, J8.12, R24.2, U5.1
VIN2: C33.1, D18.C, D19.C, J26.12, R36.2, U10.1
VIN3: C48.1, D25.C, D26.C, J38.12, R48.2, U14.1
VIN4: C63.1, D32.C, D33.C, J50.12, R60.2, U18.1
VIN5: C78.1, D39.C, D40.C, J62.12, R72.2, U22.1
VIN6: C93.1, D46.C, D47.C, J74.12, R84.2, U26.1
VIN7: C108.1, D53.C, D54.C, J86.12, R96.2, U30.1
VREG_EN: J4.1, R1.1, U3.3
VREG_EN1: J24.1, R24.1, U5.3
VREG_EN2: J36.1, R36.1, U10.3
VREG_EN3: J48.1, R48.1, U14.3
VREG_EN4: J60.1, R60.1, U18.3
VREG_EN5: J72.1, R72.1, U22.3
VREG_EN6: J84.1, R84.1, U26.3
VREG_EN7: J96.1, R96.1, U30.3
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

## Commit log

2019-05-15 Rename to Nano. Add ignore. Add panel.
    [Artemis-Nano-Panel.GBL, Artemis-Nano-Panel.GBO, Artemis-Nano-Panel.GBP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]
2019-05-20 Fixing PWM pin 7. Updating schematic symbol.
    [Artemis-Nano.brd, Artemis-Nano.sch]
2019-05-22 Fix pin 33 silk
    [Artemis-Nano.brd, Artemis-Nano.sch]
2019-06-05 Change silk to match new variant
    [Artemis-Nano.brd, Artemis-Nano.sch]
2019-06-05 Fixed TX/RX LED label swap
    [Artemis-Nano-Panel.GBL, Artemis-Nano-Panel.GBO, Artemis-Nano-Panel.GBP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]
2019-06-20 Changing bootload circuit to match what is being shipped. Add ignore.
    [Artemis-Nano.sch]
2019-06-21 Adding charge rate to sch
    [Artemis-Nano.brd, Artemis-Nano.sch]
2019-06-24 Modify BL reset circuit to work with POR, SBL, and SVL
    RTS doesn't like a 10k pull down. Remove R17. Increased R15 to 220k and reduced C21 to 0.1uF to maintain same RC time constant. Works for POR, SBL, and SVL.
    [Artemis-Nano.brd, Artemis-Nano.sch]

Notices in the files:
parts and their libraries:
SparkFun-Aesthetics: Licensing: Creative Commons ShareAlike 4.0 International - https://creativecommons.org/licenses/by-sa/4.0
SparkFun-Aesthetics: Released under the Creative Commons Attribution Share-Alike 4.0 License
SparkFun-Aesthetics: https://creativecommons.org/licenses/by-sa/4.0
